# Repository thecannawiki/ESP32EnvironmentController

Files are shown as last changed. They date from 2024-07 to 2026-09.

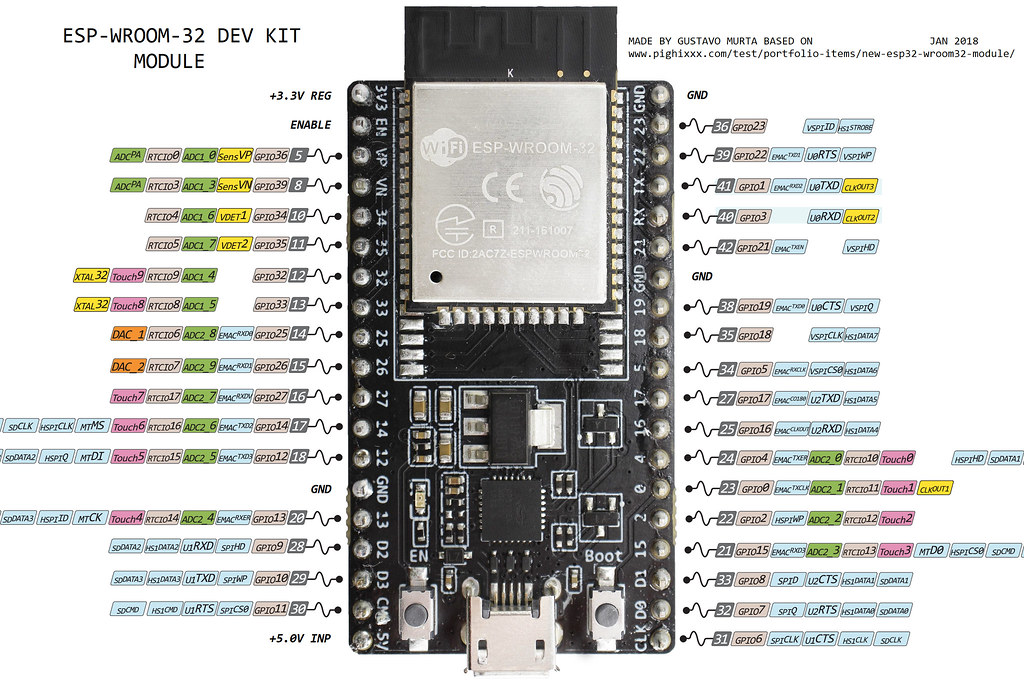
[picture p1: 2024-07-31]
esp-wroom-32-pinout.jpg

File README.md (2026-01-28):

# ESP32EnvironmentController
An environment (Temperature, humidity, Co2) controller for ESP32
Controller Hardware

Node-red interface

## Feature list:
* Automatic fan and heater control to meet target VPD
* Post live data to MQTT server
* Sensor data retrievable via HTTP
* Using a cloud MQTT Broker makes the controller accessible from anywhere you have an internet connection
* Compatibility with Node-red dashboard to display graphs of temperature, humidity, VPD, co2 levels and state of appliances being controlled.
* All data is saved to a file on the Node-red server and graphs can be generated by using the DataPlotter.py script
* Automatic watering based on hourly schedule

## Part list:
Only the ESP32 and temp/humidity sensor are strictly required
* ESP32 board
* BME280 or SCD40 temp and humidity sensor
* Motor driver board, ideally H-bridge mosfet based driver or TB6612FNG for smaller motors
* SGP30 Co2 sensor (For Co2 reading when using the BME280. SCD40 is recommended)
* Neopixel LED (optional for status indicator)
* Relay for heater control

## Installing on an ESP32
1. Download the latest release and flash the .bin to your esp32 using esptool
1. Register on MQHive for a cloud MQTT Broker or setup a MQTT broker locally.
1. Once flashing is complete the ESP will enter setup mode and create a Wifi access point. Connect to it using a phone or computer and setup your wifi and MQTT credentials. You can re-enter setup mode by shorting Pin 23 to GND
1. Connect sensors to the ESP32 (see below), and connect the esp to power either via the pins or USB port (Requires 5v 2A). Unfortunately, most PC usb ports only provide 1A so you will need a usb plug adapter or power supply.

#### Dashboard setup

1. Install Node-red on any computer. This can be a desktop, phone or raspberry pi. There are lots of options Raspberry pi the best in most cases
1. In Node-red import the dashboard.json (or Mobile.json on mobile) flow file in this repo.
1. In Node-red configure MQTT broker login details you created in step 2.

## MQTT Topics
The Topic the grow controller will publish sensor data to MQTTPUBLISHTOPIC.
The controller can be instructed by sending messages to the MQTTCONTROLTOPIC + the endpoint
e.g MQTTCONTROLTOPIC + "dehumidifier/auto"
The following endpoints are supported:
/dehumidifier/autoVpd
/dehumidifier/auto
/dehumidifier/lower
/dehumidifier/upper
/dehumidifier/target
/dehumidifier/press
/exhaust
/targetVpd

## Sensor connections:
The BME280, SGP30, SCD40 and are all I2C devices that require the following pins on the esp32 `3.3v`, `GND`, `pin 21 for SDA` and `pin 22 for SCL`
When using the BME280 and SGP30 in conjunction you will need a splitter cable

## Peripheral connections:
* An external fan be controlled via a motor driver connected to pin 12. Be sure to use the appropriate driver for your fan size
* A dehumidifier can be attached via a relay or mosfet on pin 13
* A Neopixel LED can be connected to 5v and Pin 16 where it will act as a status indicator. This mostly for development and debug purposes
* waterSensor1 pin 34;
* waterSensor2 pin 4;

## User manual

### Control modes:
There are a number of switches that effect how the controller behaves
* Autovpdfan (On/Off) - The fan is controlled automatically to reach a target VPD
* Autodehumidifer (On/Off) - The dehumidifier is automatically controlled to maintain target VPD

* Primary dehumidifier mode - Automatically control dehumidifier to maintain VPD
* Secondary dehumidifier mode - dehumidifier is controlled based on fan power. turn on when over 90%, turn off when under 50%

## Build instructions:

2. Download this repo and open in Vscode. You will need the Platformio extension installed.

## thanks to
https://maakbaas.com/esp32-soil-moisture-sensor/logs/testing-the-sensor
https://carnotcycle.wordpress.com/2012/08/04/how-to-convert-relative-humidity-to-absolute-humidity/

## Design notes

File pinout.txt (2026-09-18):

## PINOUT

int humidifierControlPin = 13;
int fanControlPin = 12;
int pump = 33;
int waterSensor1 = 34;
int waterSensor2 = 4;
int neopixelPin = 19;
int heater = 26;
heaterPWM signal 27

I2C 
    CLK 22  (purple)
    DATA 21 (orange)
    Vin (green)
    gn (blue)

         -----------------------
        |                       | 
        |                       |
        |                       |
        |     esp wroom 32      |
        |                       |
        |                       |
        |                       |
        |                       |
        |                       |
        |                       |
        |                       |
        |                       |
        |                       |
        |                       |
        |                       |
         ----------------------

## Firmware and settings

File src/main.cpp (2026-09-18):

/**********
Hardware support and default pins
  * 1 PWM fan          pin12
  * 1 dehumidifier     pin14
  * 1 humidifier       pin13
  * 1 heater           pin33
  * 1 magnetic stirrer pin26
  * 1 neopixel         pin19
  I2C connections
  SDA                  pin21 
  SCL                  pin22

*********/
#include <stdio.h>
#include <freertos/FreeRTOS.h>
#include <freertos/task.h>
#include <driver/gpio.h>
#include "sdkconfig.h"
#include <Arduino.h>
#include <globals.h>
#include <WiFiManager.h>
#include <homepage.h>
#include <mathsfunctions.h>
#include <led.h>
#include <buffer.h>
#include <mqttResponse.h>
#include <NVM.h>
#include <peripherals.h>
#include <string>
#include <sensors.h>
#include <setup_page.h>
#include "soc/soc.h"
#include "soc/rtc_cntl_reg.h"

extern "C" {
  #include "driver/touch_pad.h"
}

int sensorReadFailCount = 0;
int mqttPublishFailCount = 0;
int wifiConnectFailCount = 0;
int consecutiveMqttConnectFailCount =0;
float avgHumidityAtHumidifierTurnOn = 0;

int PIDLookback = 12; //number of samples to look back on for PID 

bool restoreDehumid = false;
bool restoreHumid = false;

char mqtturl[80] = "";
char mqttUsername[40] = "";
char mqttPass[40] = "";
char mqttPort[6] = "";

String MQTTURL = "";
String MQTTUSER = "";
String MQTTPASS = "";
String MQTTPORT = "";

// WiFiManager parameter objects
WiFiManagerParameter custom_deviceName("deviceName", "Device Name", deviceName, 40);
WiFiManagerParameter custom_mqtturl("mqttURL", "MQTT URL", mqtturl, 80);
WiFiManagerParameter custom_mqttuser("mqttuser", "MQTT username", mqttUsername, 40);
WiFiManagerParameter custom_mqttpass("mqttpass", "MQTT pass", mqttPass, 40);
WiFiManagerParameter custom_mqttport("mqttport", "MQTT port", mqttPort, 6);

uint64_t startupMillis = 0;
static const uint64_t MAX_UPTIME_MS = 48ULL * 60ULL * 60ULL * 1000ULL; // 48 hours

#define ALPHA_FALL      0.7f      // fast: follow signal down
#define ALPHA_RISE      0.1f      // slow: ignore upward blips
float ewa          = -1.0f;       // uninitialised sentinel

// Base case: one argument left
template<typename T>
void logln(T last) {
    Serial.println(last);
}

// Recursive case: print one arg, then recurse
template<typename T, typename... Args>
void logln(T first, Args... rest) {
    Serial.print(first);
    Serial.print(' ');
    logln(rest...);
}


void saveWifiManagerCustomCredentials(){
  //TODO trim these user inputs!!
  const char* deviceStr = custom_deviceName.getValue();
  if(strlen(deviceStr) > 0){
    strcpy(deviceName, deviceStr);
    preferences.putString("deviceName", deviceName);
  }
  
  const char* url = custom_mqtturl.getValue();
  if(strlen(url) > 0){
    strcpy(mqtturl, url);
    preferences.putString("mqttUrl", mqtturl);
  }

  const char* pass = custom_mqttpass.getValue();
  if(strlen(pass) > 0){
    strcpy(mqttPass, pass);
    preferences.putString("mqttPass", mqttPass);
  }

  const char* username = custom_mqttuser.getValue();
  if(strlen(username) > 0){
    strcpy(mqttUsername, username);
    preferences.putString("mqttUser", mqttUsername);
  }

  const char* port = custom_mqttport.getValue();
  if(strlen(port) > 0){
    strcpy(mqttPort, port);
    preferences.putString("mqttPort", mqttPort);
  }

}

bool refreshNetworkTime(){
  if(!getLocalTime(&timeinfo)){
    Serial.println("Failed to obtain time");
    return false;
  }
  return true;
}


void UpdateSensorJson(){
  StaticJsonDocument<420> doc;  
  char trimmedfloat[10];
  
  if(temp != 0.0f && tempBuffer.avgOfLastN(10) != 0.0f){ // First read on the scd40 can be 0
    dtostrf(temp, 5, 3, trimmedfloat);
    doc["T"] = atof(trimmedfloat);

    dtostrf(humidity, 5, 3, trimmedfloat);
    doc["RH"] = atof(trimmedfloat);
  }
  
  if(co2 != 65535){doc["co2"] = co2;}   // 65535 is the co2 value from the SCD-40 when its still warming up

  dtostrf(targetTemperature, 5, 3, trimmedfloat);
  doc["TT"] = atof(trimmedfloat);   // target temp
  // doc["tvoc"] = tvoc;
  dtostrf(calcVpd(temp, humidity), 4, 2, trimmedfloat); 
  doc["vpd"] = atof(trimmedfloat);
  dtostrf(targetVpd, 4, 2, trimmedfloat); 
  doc["TVpd"] = atof(trimmedfloat);
  doc["AF"] = int(automaticFanVpd); //auto fan
  dtostrf(targetHumidity, 5, 2, trimmedfloat);
  doc["TRH"] = atof(trimmedfloat);        //Target RH (humidity)
  dtostrf(P, 4, 2, trimmedfloat);
  doc["P"] = atof(trimmedfloat);
  // dtostrf(I, 4, 2, trimmedfloat);
  // doc["I"] = atof(trimmedfloat);
  dtostrf(D, 4, 2, trimmedfloat);
  doc["D"] = atof(trimmedfloat);
  dtostrf(HP, 4, 2, trimmedfloat);
  doc["HP"] = atof(trimmedfloat);
  dtostrf(HD, 4, 2, trimmedfloat);
  doc["HD"] = atof(trimmedfloat);

  dtostrf(HuVPD_P, 4, 2, trimmedfloat);
  doc["HuP"] = atof(trimmedfloat);
  dtostrf(HuVPD_D, 4, 2, trimmedfloat);
  doc["HuD"] = atof(trimmedfloat);

  if(!lockHVAC){
    dtostrf(fanPower, 4, 1, trimmedfloat);
    doc["F"] = atof(trimmedfloat);  //fan
    doc["DHU"] = int(dehumidiferState);    //dehumidifier state
    dtostrf(humidifierPower, 4, 2, trimmedfloat);
    doc["HU"] = atof(trimmedfloat);
  }
  doc["ADHU"] = int(automaticDehumidifier);  //auto dehumidifier
  doc["AHU"] = int(automaticHumidifier);  //auto dehumidifier
  doc["w1"] = waterSensor1State;

  doc["w2"] = w2raw;
  dtostrf( w2mean, 5, 2, trimmedfloat);
  doc["16m"] = atof(trimmedfloat);
  doc["ewa"] = ewa;


  dtostrf(heaterPower, 4, 2, trimmedfloat);
  doc["H"] = atof(trimmedfloat);
  doc["w1T"] = w1maxWaterSensorVal;
  doc["w2T"] = w2maxWaterSensorVal;
  doc["VPDMode"] = int(vpdMode);
  doc["ram"] = ESP.getFreeHeap();
  doc["LFB"] = heap_caps_get_largest_free_block(MALLOC_CAP_DEFAULT);
  // Serial.printf("Largest free block: %u bytes\n", heap_caps_get_largest_free_block(MALLOC_CAP_DEFAULT));

  serializeJson(doc, sensorjson);
}

void initNonVolitileMem(){
  // TODO default values are duplicated here
  preferences.begin("controller", false); 
  fanPower = preferences.getFloat("fanPower", 0.0f);
  fanPowerLimiter = preferences.getFloat("fanPowerLimiter", 1.0f);
  dehumidiferState = preferences.getBool("dehumidifier", dehumidiferState);
  autoHeater = preferences.getBool("autoHeater", autoHeater);
  P = preferences.getFloat("P", 0.4f);
  I = preferences.getFloat("I", 0.3f);
  D = preferences.getFloat("D", 3.0f);
  HP = preferences.getFloat("HP", 1.0f);
  HD = preferences.getFloat("HD", 0.1f);
  HuVPD_P = preferences.getFloat("HuP", 3.0f);
  HuVPD_D = preferences.getFloat("HuD", 1.0f);
  humidifierPower = preferences.getFloat("HuP", 0.0f);
  automaticDehumidifier = preferences.getBool("autoDehumid", automaticDehumidifier);
  automaticFanVpd = preferences.getBool("autoVpd", automaticFanVpd);
  dehumidifierPrimaryMode = preferences.getBool("primaryHumid", dehumidifierPrimaryMode);
  dehumidifierForTemp = preferences.getBool("dehumidAutoTemp", dehumidifierForTemp);
  targetVpd = preferences.getFloat("tvpd", 1.0f);
  targetTemperature = preferences.getFloat("ttemp", targetTemperature);
  targetHumidity = preferences.getFloat("targetHumidity", targetHumidity);
  // heaterState = preferences.getBool("headerState", false);
  softMaxFan = preferences.getFloat("softMaxFan", 100.0f);
  softMinFan = preferences.getFloat("softMinFan", 0.0f);
  heaterTempMode = preferences.getFloat("HFT", heaterTempMode);
  humidifierState = preferences.getBool("humidifier", false);
  automaticHumidifier= preferences.getBool("AHU", true);
  vpdMode = preferences.getBool("VpdMode", true);
  w1maxWaterSensorVal = preferences.getInt("w1Max", 1800);
  w2maxWaterSensorVal = preferences.getInt("w2Max", 20);
  setupMode = preferences.getBool("setupMode", false);
  heaterMaxPower = preferences.getInt("heaterMaxPower", heaterMaxPower);
  strncpy(deviceName, preferences.getString("deviceName", "").c_str(), sizeof(deviceName));
  deviceName[sizeof(deviceName) - 1] = '\0';  // ensure null-terminated 
  MQTTURL = preferences.getString("mqttUrl", "");
  MQTTUSER = preferences.getString("mqttUser", "");
  MQTTPASS = preferences.getString("mqttPass", "");
  MQTTPORT = preferences.getString("mqttPort", "");
  
  UpdateSensorJson();
  Serial.println("retrieved from NVM: ");
  Serial.println(sensorjson);
}

//Handlers for web requests
// void getSensorReadingsWeb(AsyncWebServerRequest *request){
//   UpdateSensorJson();
//   request->send_P(200, "application/json", sensorjson);
// }



void longPWMloop(void *parameter){ // 0-1000
  int *power;
  power = (int *) parameter;
  int totalwidth = 50;
  int highcount = totalwidth * int(power) / 1000; 
  //int halfPower = (softMaxPWM - 1)/ 2 + 1; //sweet trick to divide and get an int
  int count = 0;
  while(true){ 
    if(count < highcount * 2){ //for halfpower change
      //rampUpFan(50);
      ledcWrite(fanPWMchannel, 20);
    } else {
      ledcWrite(fanPWMchannel, 0);
    }
    count+=1;
    if(count > totalwidth){
      count = 0;
    }
    if(fanChanged){  vTaskDelete( NULL ); Serial.println("fan task killed");}
    vTaskDelay(2000);
  }
}

void kickFan(){
  ledcWrite(fanPWMchannel, maxPWMval);
  delay(160);
  float curr_val = map(fanPower *10, 0, 1000, 0, fanPowerLimiter * maxPWMval);
  ledcWrite(fanPWMchannel, curr_val);
}

void updateFanPower(){ /// 0-100 to 1 dp. Value then gets converted to int 0-1000 by multiplying by 10
  if(heaterPower >10 && fanPower >15){
    fanPower = 15;
  }
  
  int powerVal  = fanPower * 10;    // 0-1000
  if(powerVal>1000){powerVal = 1000;}
  if(powerVal<0){powerVal = 0;}

  if(powerVal == 0){
    ledcWrite(fanPWMchannel, 0);
  } else{
    powerVal = map(powerVal, 0, 1000, 0, fanPowerLimiter * maxPWMval);


    int moveSize = 200;
    float fanDiff = powerVal - lastPowerVal;

    // Serial.print("diff");
    // Serial.println(fanDiff);

    if(fanDiff > moveSize){
      Serial.println("ramping up fan");
      Serial.print(fanDiff/moveSize);
      Serial.println(" steps");

      for(int i=1; i<(fanDiff/moveSize);i++){ //increase fan power in increments of moveSize
        int val = i*moveSize;
        Serial.print("fan ramp up ");
        Serial.println(val);

        ledcWrite(fanPWMchannel, map(val, 0, 1000, 0, fanPowerLimiter * maxPWMval));
        vTaskDelay(300);
      }
    } 

    // Serial.print("prev fan value ");
    // Serial.print(fanBuffer.avgOfLastN(1));
    // Serial.print(" ");
    if(fanBuffer.avgOfLastN(1) <= 4 && fanPower > 4){
      kickFan();
    }

    ledcWrite(fanPWMchannel, map(powerVal, 0, 1000, 0, fanPowerLimiter * maxPWMval));
  }

  preferences.putFloat("fanPower", fanPower);
  saveToNVM();
  // Serial.println("fan updated");
  lastPowerVal = powerVal;
  //esp_task_wdt_reset();
}


void freezeWatchdog(void * parameter){
  int lastloopCounter=0;
  while(true){
    lastloopCounter = loopCounter;
    vTaskDelay(20000); //20 seconds
    if(loopCounter == lastloopCounter){
      Serial.println("Controller is frozen!!");
      ESP.restart();
    } else {
      Serial.print("WD ");
    }
  }
}

void reconnectWifi(){
  wifiMulti.run();
  int waitCount = 0;
  Serial.println("");
  Serial.print("Connecting wifi");
  while (WiFi.status() != WL_CONNECTED){
    Serial.print(".");
    delay(2000);
    waitCount++;
    if(waitCount > 10){
      Serial.print("");
      break;
    }
  }
}

void mqttreconnect() {
  if(WiFi.status() != WL_CONNECTED){
    logln("can't reconnect mqtt. No Wifi connection");
    return;
  }
  int errcount = 0;
  // Loop until we're reconnected.. If we loop forever here the watchdog will restart
  while (!mqttclient.connected()) {
    espClient.stop();
    Serial.println("Attempting MQTT connection...");
    
    bool connectSuccess = mqttclient.connect(WiFi.macAddress().c_str(), MQTTUSER.c_str(), MQTTPASS.c_str());
    if (connectSuccess) {
      consecutiveMqttConnectFailCount = 0;
      Serial.println("connected");
      // Subscribe
      std::string controlTopic;
      controlTopic = MQTTCONTROLTOPIC;
      mqttSubscribeTopics(controlTopic);
    }
    else {
        int errstate = mqttclient.state();
        logln("failed, mqtt client state=", errstate,"will try again");
        if(errstate==5){
            logln("Check credentials");
        }
        logln("mqttconnect", "mqtt url:",MQTTURL,"mqtt username:", MQTTUSER,"pass:",MQTTPASS, "mqtt port:",MQTTPORT);
        errcount++;
        consecutiveMqttConnectFailCount ++;
    }

    if(consecutiveMqttConnectFailCount> 10){
      logln("Too many fails getting mqtt connection.. restarting");
      ESP.restart();
    }
    
    if(errcount>1){
      break;
    }
    vTaskDelay(100);
  }
}


void mqttPublishSensorData(){
  UpdateSensorJson();
  bool success = mqttclient.publish(MQTTPUBLISHTOPIC, sensorjson, false);
  if(success){
    mqttPublishFailCount = 0;
    Serial.print("-> ");
  } else {
    mqttPublishFailCount +=1;
    Serial.print("MQTT send failed with"); Serial.println(sensorjson);
    if(mqttPublishFailCount > 5){
      Serial.println("mqtt publish failed 5 times. Restarting");
      ESP.restart();
    }
  }
}

void mqttMessageReceived(char* topic, byte* message, unsigned int length) {
  //esp_task_wdt_reset();
  String messageTemp;
  Serial.println("");
  
  for (int i = 0; i < length; i++) {
    messageTemp += (char)message[i];
  }

  logln("got mqtt ", topic, " | ", messageTemp);
  mqttHandle(topic, messageTemp);
}

void operateDehumidifierOnBounds(){   //if humidity too high turn on the dehumidifier and vice-versa
  if(humidity>=(float)-1){
    Serial.print("O ");
    if(dehumidiferState){ //dehumidifier on
        if(humidity <= lowerHumidityBound){
          setDehumidifierState(false);
        }
    } else{ //dehumidifer off
      if(humidity >= upperHumidityBound){
        setDehumidifierState(true);
      }
    }
  }
}

void operateDehumidifierOnFanUsage(){
  if(!dehumidiferState){
    if (fanPower >= softMaxFan * 0.5f){ // 50% of max fan allowed 
      setDehumidifierState(true);
    }
  } else {
    if (fanPower <= softMaxFan * 0.2f){ // 20% of max fan allowed 
        setDehumidifierState(false);
    }
  }
}

void operateHumidifier(){
  float humidityError = humidity - targetHumidity;
  float dir = humidityBuffer.PID_D_Diff(12);
  float avg_hu_err = errorBuffer.avgOfLastN(24);    // 2 mins
  logln("hu", dir);
  int xMinutes = 8; // change this

  //handle pause
  if (humidifierPauseTime != 0){
    time_t now = time(nullptr);
    if(now >= humidifierPauseTime){
      logln("Unpausing humidifer");
      humidifierPauseTime = 0;
    } else {
      logln("Humidifer paused", humidifierPauseTime- now, "remaining");
      return;
    }
  }

  // Too wet!
  if(humidityError > 2.5f){
    setHumidifierState(false);
    return;
  }
  


  //check if humidifer is effective
  int lookbackSecs = 180; // 3 mins
  int onForLast = humidifierStateBuffer.countVal(1, lookbackSecs); 
  logln("Humidifier on for ", lookbackSecs, " secs humiditify diff since last turn on ", humidifierStateBuffer.avgOfLastN(20) - avgHumidityAtHumidifierTurnOn);
  //check humidity has raised a reasonable amount
  if(humidifierState && onForLast > lookbackSecs && avgHumidityAtHumidifierTurnOn && humidifierStateBuffer.avgOfLastN(20) - avgHumidityAtHumidifierTurnOn <= 10){
    logln("Humidifier on for ", lookbackSecs, " secs humiditify diff ", humidifierStateBuffer.avgOfLastN(20) - avgHumidityAtHumidifierTurnOn, "humidifier uneffective");
    humidifierPauseTime = time(nullptr) + (10 * 60);
    setHumidifierState(false);
    logln("pausing humidifer for ", 10);
    return;

  }

  //check if humidifier is oscillating
  // int onForLast = humidifierStateBuffer.countVal(1, 120); // 2 mins
  // logln("hu on for", onForLast, "secs in last 2 min");
  // float onPercent = float(onForLast) / 120.0f;
  // logln("on percent", onPercent, "avg hu", avg_hu_err);
  // if(onPercent >= 0.3f && onPercent <= 0.7f && avg_hu_err > -0.8f && avg_hu_err < 0.8f){ //in a good range but using the humidifier on and off
  //   logln("HUMIDIFIER OSCILLATION DETECTED!");
  //   humidifierPauseTime = time(nullptr) + (xMinutes * 60);
  //   setHumidifierState(false);
  //   logln("pausing humidifer for ", xMinutes);
  //   return;
  // }


  if(humidifierState){

    if(humidityError >= 0.0f && dir >=1.0f){
        setHumidifierState(false);
    }

  } else {
    if(humidityError <= -5.0f || (humidityError <= -2.0f && dir <=-1.0f)){
        setHumidifierState(true);
        avgHumidityAtHumidifierTurnOn = avg_hu_err;

    }
  }  
}

void operateDehumidifierOnTempBounds(){
 if(temp>=(float)-1){
    if(temp <= 24){
      setDehumidifierState(true);
    }
    if(temp >= 26){
      setDehumidifierState(false);
    }
 }
}

float calcDfan(){
  int lookback_length = 8;    //good for fast oscillations 

  int lookback_index = humidityBuffer.newest_index-lookback_length;
  int cindex = humidityBuffer.newest_index-1;
  if(lookback_index < 0){
    lookback_index = humidityBuffer.size() + lookback_index;
  }
  if(cindex < 0){
    cindex = humidityBuffer.size() + cindex;
  }
  float old = humidityBuffer.data[lookback_index];
  float current = humidityBuffer.data[cindex];
  if(old ==-1.0f || old == 0.0f || current ==-1.0f || current== 0.0f){
    return 0;
  }

  float diff = ( current - old) / lookback_length;
  
  float Dfan = D * diff; 

  // Serial.print("D = ");
  // Serial.print(Dfan);
  // Serial.print(" (diff ");
  // Serial.print(diff);
  if(diff > 0){
    Serial.println("RH trending up");
  } else {
    Serial.println("RH trending down");
  }
  // Serial.println(")");

  return Dfan;
}

float calcIfan(){
  float sum = 0;
  int lookback = 24;

  for(int i=1; i<lookback; i++){
    int cindex = errorBuffer.newest_index-i;
    if(cindex < 0){
      cindex = errorBuffer.size() + cindex;
    }
    
    float c = errorBuffer.data[cindex];
    sum+=c;
  }

  float Ifan = (I * sum) /10; //for tuning
  
  // Serial.print("I = ");
  // Serial.print(Ifan);
  // Serial.print(" (integral ");
  // Serial.print(sum);
  // Serial.println(")");

  return Ifan; 
}

bool fanStruggle(){
  int lookback = 500;
  bool fanStruggle = false;
  int votes = 0;
  float val = 0;
  for(int i=1; i<=lookback; i++){
    int index = (fanBuffer.newest_index - i + fanBuffer.size()) % fanBuffer.size();
    val  = fanBuffer.data[index];
    if(val >= softMaxFan){
      votes = votes + 1;
    }
  }
  logln("fan struggle votes", votes, "/",lookback);
  if(votes == lookback){
    fanStruggle = true;
  }

  return fanStruggle;
}

bool heaterOnFor(int lookback){ // Heater was on for entire lookback time?
  int votes = 0;
  for(int i=1; i<=lookback; i++){
    int index = (heaterStateBuffer.newest_index - i + heaterStateBuffer.size()) % heaterStateBuffer.size();
    float val  = heaterStateBuffer.data[index];
    if(val == 0){break;}
    votes = votes + val;
  }
  logln("heater on for last", votes, "secs");
  if(votes == lookback){
    return true;
  }
  return false;
}

void heaterSensorSafety(){
  if(heaterPower > 0){
    // float tempDirection = PIDDiff(tempBuffer,24); //24 * 5 = 120
    float tempDirection = tempBuffer.PID_D_Diff(24);
    bool heaterOn = heaterOnFor(120);
    Serial.print("temp diff");
    Serial.println(tempDirection, 6);
    if(heaterOn && tempDirection < -0.01f && errorBuffer.avgOfLastN(3) > 2.5f){
      logln("Disabling heater. Temp not rising and not in target range");
      setHeaterState(false);
      return;
    }
  }
}


float heaterTempPID(){
  logln("heater PID for temp");
  float error = targetTemperature - temp;
  logln("error", error);
  //P
  float Pterm = HP * error;
  logln("heater P", Pterm);
  float Dterm = PIDDTerm(8) * HD;

  float newP = heaterPower + Pterm + Dterm;
  
  return newP;
}

float heaterVPDPID(){
  logln("heater PID for VPD");
  float vpd = calcVpd(temp, humidity);
  float error = targetVpd - vpd;
  logln("vpd error", error);
  //P
  float Pterm = HP * error;
  logln("heater P", Pterm);
  float Dterm = PIDDTerm(8) * HD;

  float newP = heaterPower + Pterm + Dterm;
  
  return newP;
}

float heaterHumidPID(){
  logln("heater PID for humid");
  float humidityError = humidity - targetHumidity;
  //P
  float Pterm = HP * humidityError;
  float Dterm = PIDDTerm(8) * HD;

  float newP = heaterPower + Pterm + Dterm;
  return newP;
}

void heaterPID(){
  float newP = 0;
 
    // if(!heaterTempMode && fanStruggle() && errorBuffer.avgOfLastN(3) > 2)
    // {
    //   newP = heaterHumidPID();
    // }
    // else if (heaterTempMode && tempBuffer.avgOfLastN(5) < targetTemperature)
    // {
    //   newP = heaterTempPID();
    // }
  if(heaterTempMode){
    newP=heaterTempPID();
  } else{
    if(vpdMode){
      newP = heaterVPDPID();
    } else {
      newP = heaterHumidPID();
    }
  }
  

  if(newP <=0){newP = 0.0f;}
  if(newP >=100){newP = 100;}
  if(newP > heaterMaxPower){ newP = heaterMaxPower;}

  if(abs(newP - heaterPower) > 0.0f){
    heaterPower = newP;
    updateHeaterPower();
    // logln("new heater:", newP);
  }
  logln("Heater PID:", heaterPower);

}

float humidifierPID_VPD(){
  logln("humidifier PID for VPD");
  float vpd = calcVpd(temp, humidity);
  float error = targetVpd - vpd;
  logln("vpd error", error);
  //P
  float Pterm = HuVPD_P * error;
  logln("humidifer P", Pterm);
  float Dterm = PIDDTerm(8) * HuVPD_D;

  float newP = humidifierPower + Pterm + Dterm;

  if(newP <=0){newP = 0.0f;}
  if(newP >=100){newP = 100;}

  
  return newP;
}

float humidifierPID_HU(){
  // logln("humidifier PID for humid");
  float humidityError = targetHumidity - humidity;
  //P
  float Pterm = HuVPD_P * humidityError;
  float Dterm = PIDDTerm(8) * HuVPD_D;

  float newP = humidifierPower + Pterm + Dterm;

  if(newP <=0){newP = 0.0f;}
  if(newP >=100){newP = 100;}
  return newP;
}
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
extern "C" void app_main()
{
    // initialize arduino library before we start the tasks
    initArduino();
    setup();

    xTaskCreatePinnedToCore(mainloop, "main", 24*1024, NULL, 12, NULL, 1);
    xTaskCreate(mqttLoop, "mqttHandler", 4000, 0, 1, &mqttTaskHandle);
    xTaskCreate(freezeWatchdog, "watchdog", 1000, 0, 0, &freezewatchdogTaskHandle);
    
}

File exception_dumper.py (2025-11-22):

import serial
import datetime
from collections import deque

PORT = "COM5"     # Change as needed
BAUD = 115200             # Change as needed
RESET_STRING = "ets"
PRE_LINES = 40
POST_LINES = 20

def main():
    ser = serial.Serial(PORT, BAUD, timeout=0.1)

    # Keeps rolling log of previous PRE_LINES lines
    history = deque(maxlen=PRE_LINES)

    post_capture_count = 0
    post_buffer = []

    while True:
        raw = ser.readline()
        if not raw:
            continue

        try:
            line = raw.decode(errors="replace")
        except:
            continue

        print(line,end="")  # Log live to terminal

        # If currently capturing post-reset lines
        if post_capture_count > 0:
            post_buffer.append(line)
            post_capture_count -= 1

            # If finished capturing POST_LINES, write file
            if post_capture_count == 0:
                save_capture(history, post_buffer)
                post_buffer = []
            continue

        # Add line to rolling history
        history.append(line)

        # Detect reset
        if RESET_STRING in line:
            print("\n--- RESET DETECTED ---\n")
            post_capture_count = POST_LINES


def save_capture(before, after):
    timestamp = datetime.datetime.now().strftime("%Y-%m-%d_%H-%M-%S")
    filename = f"reset_captures/reset_capture_{timestamp}.log"

    with open(filename, "w") as f:
        f.write("=== PRECEDING LINES ===\n")
        for l in before:
            f.write(l + "\n")

        f.write("\n=== RESET TRIGGER LINE + FOLLOWING LINES ===\n")
        for l in after:
            f.write(l + "\n")

    print(f"\nSaved reset capture to {filename}\n")


if __name__ == "__main__":
    main()

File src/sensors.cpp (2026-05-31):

#include <globals.h>
#include <peripherals.h>
#include <buffer.h>
#include <scd4.h>
#include <bme.h>

int sensorMountFailCount = 0;

template<typename T>
void logln(T last) {
    Serial.println(last);
}

// Recursive case: print one arg, then recurse
template<typename T, typename... Args>
void logln(T first, Args... rest) {
    Serial.print(first);
    Serial.print(' ');
    logln(rest...);
}

void i2cScan(){
  byte error, address; //variable for error and I2C address
  Serial.println("Scanning...");

  int nDevices = 0;
  for (address = 1; address < 127; address++ ){

    // The i2c_scanner uses the return value of
    // the Write.endTransmisstion to see if
    // a device did acknowledge to the address.
    Wire.beginTransmission(address);
    error = Wire.endTransmission();

    if (error == 0){
      Serial.print("I2C device found at address 0x");
      if (address < 16)
        Serial.print("0");
      Serial.print(address, HEX);
      Serial.println("  !");

      switch(address){
        case 118:
          bmeMounted = true;
          Serial.println("bme280 found");
          break;
        case 98:
          SCD40Mounted = true;
          Serial.println("scd40 found");
          break;
      }

      nDevices++;
    }
    else if (error == 4)
    {
      Serial.print("Unknown error at address 0x");
      if (address < 16)
        Serial.print("0");
      Serial.println(address, HEX);
    }
  }
  if (nDevices == 0){
    Serial.println("No I2C devices found\n");
  } else {
    Serial.println("done\n");
    if(SCD40Mounted){
      sensorPref = SCD4;
      logln("Sensor set to SCD40");
      return;
    }
    if(bmeMounted){
      sensorPref = BM280_SGP30;
      logln("Sensor set to BME280");
    }
  }
}

    bool initSensors(){
        if(sensorPref == SCD4){
          return initScd40();

        }
        else if(sensorPref == BM280_SGP30){
            return initBmeSgp();
        }
        return false;
    }


    bool getSensorReadings(){   //This can be done every 5 seconds
        if(sensorPref == SCD4){
            return readScd40();
        }
        else if(sensorPref == BM280_SGP30){
            return readBmeSgp();
        }

        return false;
    }

bool checkSensors(){
  if(sensorPref == SCD4){
    if(!SCD40Mounted){
      bool ok = initSensors();
      if(!ok){
        sensorMountFailCount +=1;
      } else {
        sensorMountFailCount = 0;
      }
      return ok;
    } else {
      return true;
    }

  } else if (sensorPref == BM280_SGP30)
  {
    if(!bmeMounted){
      bool ok = initSensors();
      if(!ok){
        sensorMountFailCount +=1;
      } else {
        sensorMountFailCount = 0;
      }
      return ok;
    } else {
      return true;
    }
  }


  if(sensorMountFailCount >= 8){
    Serial.println("Failed to connect sensors >4 times in a row. SAFETY MODE");
    setHeaterState(false);
    i2cScan();
    temp = -1;
    humidity = -1;
    fanPower = 30;
    fanChanged = true;
  }


  float num = 0;
  int dupecount = 0;
  for(int i=1; i<5; i++){
    int index = (humidityBuffer.newest_index - i + humidityBuffer.size()) % humidityBuffer.size();
    float c  = humidityBuffer.data[index];
    if(c == num){
        dupecount++;
    }
    num = c;
  }

  if(dupecount > 4){
    setHeaterState(false);
    Serial.println("reinit sensors");
    initSensors();
  }

  return false;
}

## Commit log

2022-06-01 Instructions and node-red flow
2022-06-01 cleaned up LED animations
2022-06-28 doesnt crash when changing fan power a lot
    [main.cpp]
2022-07-08 Fixed bugs where dehumidifier state was incorrect
    [DataPlotter.py, main.cpp]
2022-08-03 mobile formatted node-red flow
2022-09-25 exhaust fan improvements
2022-10-18 fixed bug where PWM fan task lives on after fanPower changes
    [main.cpp]
2023-02-27 Support for sensor choice of bme280 or scd40
2023-10-04 seperated mqtt, bigger fan support
2024-01-10 software fan max, different dehumidifier operating mods
2024-07-31 water pump, better resilience to sensor mount fail
    [bme.cpp, globals.cpp, main.cpp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]
2024-10-23 temp and humidity buffers, heater, water pump
2025-01-30 Readme improvement, trans test no longer blocking, general refactoring
    [globals.cpp, main.cpp, mqttResponse.cpp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]
2025-05-20 Controller main board
    [main_board-B_Cu.gbr, main_board-B_Mask.gbr, main_board-B_Paste.gbr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]
2025-05-24 switching power supply
    [main_board.kicad_pcb]
2025-06-04 board 3
    [main_board.kicad_pcb]
2025-06-13 Use more memory for mqtt messages, fan stalling workaround, better wifi connection recovery, PID tuning
    [globals.cpp, main.cpp, peripherals.cpp]
2025-09-06 Hardware v1.1.1
    [main_board-B_Cu.gbr, main_board-B_Mask.gbr, main_board-B_Paste.gbr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]
2025-09-08 float vals in mqtt output, better heater
2025-09-23 switch for vpd or RH setpoint
2025-11-05 No hardcoded settings but also i2c buggin
    [bme.cpp, globals.cpp, main.cpp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]
2025-11-22 migrate to esp idf + arduino
    [partitions.csv]
2026-01-28 Buffer of any size, heater/fan struggle logic, time sensitive humidifier logic
2026-02-09 1.2.0 board
2026-02-15 Proper Heater PID
2026-03-11 faster water sensor, better humidifier handling
2026-05-31 Better cap. water sensor, stability fixes, humidifier PID
    Sensor warm up time + pre-populating sensor buffers with last known values instead of 0
    [bme.cpp, globals.cpp, main.cpp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]
2026-09-18 more precise fan power limiter, re-add fan struggle check with stall fix
    [globals.cpp, main.cpp, mqttResponse.cpp]
